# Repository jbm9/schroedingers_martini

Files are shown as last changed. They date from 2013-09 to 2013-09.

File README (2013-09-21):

schroedingers_martini
=====================

Schroedinger's Martin -- A submission for BarBot 2013.75

This is the work of Jonathan Foote and Josh Myer <josh@joshisanerd.com>

This repository contains the atoms and bits that make up
Schroedinger's Martini.

Contents:

atoms/ -- The 3D printed bits
bits/ -- The firmware, currently Arduino-driven

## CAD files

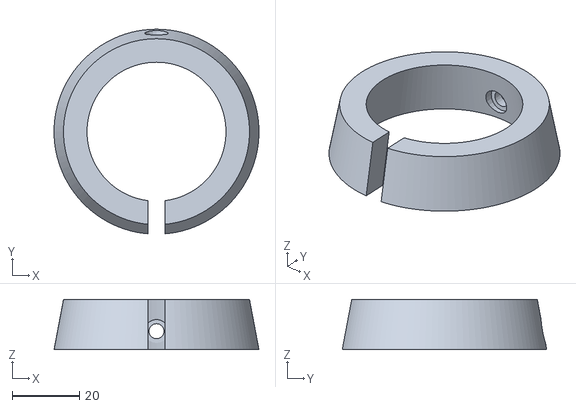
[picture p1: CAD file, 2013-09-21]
atoms/cup_clip.stl
61.0 x 60.9 x 15.0

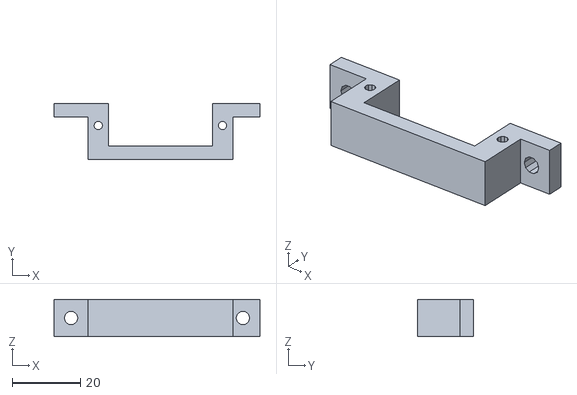
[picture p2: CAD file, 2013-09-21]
atoms/motor_clip.stl
60.5 x 16.5 x 11.0

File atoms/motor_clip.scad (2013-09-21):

/*
 * motor_clip.scad: the clip for the motors
 */

scale=25.4; // measurements are in inches...

width=30 + 0.5; // width of motor body
height=12 + 0.5; // "height" of motor on its side
depth=11;         // how deep to make the bracket

mountD = 2.5; // diameter of mounting screw
mountDX = 3; // center dx from edge
mountDY = 6;

flange=10; // 10mm flange
hole = 4; // diameter of hole
walld = 4; // how thick to make the walls

union() {

  // left flange
    translate([0,
	       height,
	       0]) 
  difference() {
      cube([flange+2*mountDX, walld, depth]);
      translate([flange/2,
		 -0.5,
		 depth/2])
	rotate([-90,0,0]) # cylinder(r=walld/2, h=walld*2, $fn=10);
    }

  // clip body
#  translate([flange,
	     0,
	     0])
    difference() {
    cube([2*mountDX+width+2*mountDX,
	  walld+height,
	  depth]);
    translate([2*mountDX,walld,0]) cube([width,height+1,depth]);

    // screwdowns for the motor's brackets
    translate([mountDX,
	       walld+mountDY,
	       0])
      cylinder(r=mountD/2, h=depth, $fn=10);

    translate([width+3*mountDX,
	       walld+mountDY,
	       0])
      cylinder(r=mountD/2, h=depth, $fn=10);

    


  }

  // right flange
  translate([2*mountDX+flange+width,
	     height,
	     0]) 
  difference() {
    cube([flange+walld, walld, depth]);
      translate([walld+flange/2,
		 -0.5,
		 depth/2])
	rotate([-90,0,0]) # cylinder(r=walld/2, h=walld*2, $fn=10);
  }


}

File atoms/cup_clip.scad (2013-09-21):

dBig = 50;
dSmall = 30;
hCup = 53;

slope = (dBig - dSmall)/hCup/2;
echo(slope);


holeD = 4.5; // hole for mounting screw
screwDepth = 2.5; // depth of screw
postD = 7; // diameter of post
postH = 3.5;  // depth of post

minT = 2; // minimum thickness of side

slotW = 5; // width of slot for screwdriver

cBig = 47/2;
h = 15;
cSmall = cBig-h*slope;

ringW = 7;

echo(cBig);
echo(cSmall);

difference() {
  cylinder(h, cBig+ringW, cSmall+ringW, $fn=100);
  cylinder(h, cBig, cSmall, $fn=100);


  // screwdiver/grip slot
  translate([-slotW/2,-cBig-ringW-2, 0]) cube([slotW,ringW+10,h]);

  // mounting post hole
#  translate([0, cBig+ringW, minT+postD/2]) rotate([90, 0,0]) 
  union() { 
    cylinder(r=postD/2, h=postH, $fn=20);
    cylinder(r=holeD/2, h=ringW+2, $fn=20);
    translate([0,0,postH+screwDepth]) cylinder(r=postD/2, h=20, $fn=20);
  }
}

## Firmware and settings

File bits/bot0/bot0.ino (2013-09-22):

/* Local Variables:  */
/* mode: c++         */
/* comment-column: 0 */
/* End:              */


#include <Servo.h>

enum SMPins {
  PIN_GEIGER = 2, // This must be 2 or 3 for interrupts, see attachInterrupt()

  PIN_BUTTON = 4,    // Input for button, any digital line
  PIN_BUTTON_LED = 5, // PWM'able output for button LED

  // Servo is going to eat 9/10 as PWM outputs anyway, so we use those
  PIN_SERVO_L = 9,  // Output for left servo
  PIN_SERVO_R = 10, // Output for right servo

  PIN_DIAGNOSTIC = 13, // "diagnostic" LED
};

enum ServoJunk {
  ServoLeftStart = 5,
  ServoLeftStop = 110,

  ServoRightStart = 175,
  ServoRightStop = 60,
};

#define N_SERVO_STEPS 15

int servo_steps[N_SERVO_STEPS] = { 0, 10, 20, 35, 50,
                                   58, 66, 74, 82, 90,
				   95, 100, 105, 108, 110, };


enum Delays {
  DELAY_READINGS = 5000, // 5s of blinky to get a reading
};




Servo servo_left;
Servo servo_right;


volatile int geiger_counter;

void geiger_isr() {
  geiger_counter++;
}


void pour(uint8_t which_servo) {
  uint8_t led_intensity = 255; // How bright to pound the LED for the showy bits below
  uint8_t brightness = 128;

  for (int i = 0; i < N_SERVO_STEPS; i++) {

    if (which_servo) {
      servo_right.write(ServoRightStart - servo_steps[i]);
      Serial.println(ServoRightStart - servo_steps[i]);
    } else {
      servo_left.write(ServoLeftStart + servo_steps[i]);
      Serial.println(ServoLeftStart + servo_steps[i]);
    }
    
    analogWrite(PIN_BUTTON_LED, brightness);
    brightness -= 255/(2*N_SERVO_STEPS);
    delay(100);
  }

  Serial.println("Returning cup to zero");
  delay(250);

  Serial.println("Returning cup to zero");
  for (int i = N_SERVO_STEPS-1; i >= 0; i--) {
    if (which_servo) {
      servo_right.write(ServoRightStart - servo_steps[i]);
      Serial.println(ServoRightStart - servo_steps[i]);
    } else {
      servo_left.write(ServoLeftStart + servo_steps[i]);
      Serial.println(ServoLeftStart + servo_steps[i]);
    }
    analogWrite(PIN_BUTTON_LED, brightness);
    brightness -= 255/(2*N_SERVO_STEPS);
    Serial.println(brightness);
    delay(100);
  }

  analogWrite(PIN_BUTTON_LED, led_intensity);
  delay(100);

}



void setup() {
  Serial.begin(9600);
  //  Serial.println("Schroedinger's Martini Bot v0.1");

  geiger_counter = 0;
  attachInterrupt(0, geiger_isr, RISING);


  pinMode(PIN_BUTTON, INPUT);
  digitalWrite(PIN_BUTTON, 1); // turn on pull-up

  pinMode(PIN_BUTTON_LED, OUTPUT);

  pinMode(PIN_DIAGNOSTIC, OUTPUT);

  servo_left.attach(9);
  servo_right.attach(10);

  servo_left.write(ServoLeftStart);
  servo_right.write(ServoRightStart);

  pour(0);
  pour(1);

}




void loop() {
  Serial.print("Loop! ");
  //  Serial.println(geiger_counter);
  geiger_counter = 0;

  /* ****************************** */
  // Breathing while waiting for button push

  uint8_t do_breathe = 1;
  uint8_t brightness = 0;

  //  Serial.println("Waiting");

  while(do_breathe) { // TODO Make LED "breathe" while waiting for input: http://sean.voisen.org/blog/2011/10/breathing-led-with-arduino/

    for (brightness = 0; do_breathe && brightness < 245; brightness += 10) {
      analogWrite(PIN_BUTTON_LED, brightness);
      do_breathe = digitalRead(PIN_BUTTON);
      delay(100);
    }

    for (; do_breathe && brightness >= 10; brightness -= 10) {
      analogWrite(PIN_BUTTON_LED, brightness);
      do_breathe = digitalRead(PIN_BUTTON);
      delay(80);
    }
  }


  /* ****************************** */
  // Silly showmanship while reading the geiger counter data

  Serial.print("Reading: ");

  uint8_t led_intensity = 255; // How bright to pound the LED for the showy bits below

  geiger_counter = 0;

  for (int delay_counter = 0; delay_counter < DELAY_READINGS/200; delay_counter++) {
    analogWrite(PIN_BUTTON_LED, led_intensity);
    delay(100);
    analogWrite(PIN_BUTTON_LED, 0);
    delay(100);
  }

  /* ****************************** */
  // Decide which servo to pour from
  //  Serial.println(geiger_counter);
  uint8_t which_servo = geiger_counter & 1;

  /* ****************************** */
  // Commence the jigglin'!

  Serial.print("Pouring: ");
  //  Serial.println(which_servo ? "R" : "L");

  pour(which_servo);


  digitalWrite(PIN_DIAGNOSTIC, 1);
  delay(20);
  digitalWrite(PIN_DIAGNOSTIC, 0);
  delay(20);

  if (which_servo) {
    digitalWrite(PIN_DIAGNOSTIC, 1);
    delay(20);
    digitalWrite(PIN_DIAGNOSTIC, 0);
    delay(20);
  }

}

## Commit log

2013-09-21 Adds mechanicals
    [cup_clip.scad, cup_clip.stl, motor_clip.scad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]
2013-09-22 Tweaks and bugfixes to get to first working rev
    [bot0.ino]
